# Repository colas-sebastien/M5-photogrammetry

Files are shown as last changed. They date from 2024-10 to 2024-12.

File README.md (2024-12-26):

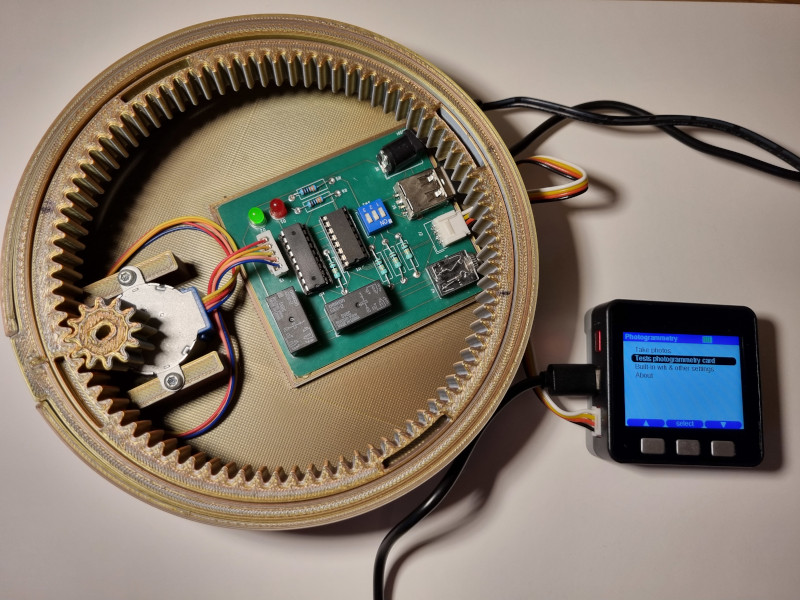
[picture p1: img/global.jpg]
Project photo

# M5 Photogrammetry Project
_Hardware and Software to do low cost photogrammetry_

## Introduction

Based on the following project [Arduino controlled photogrammetry 3D-scanner](https://www.thingiverse.com/thing:3958326) I decided to replace the arduino by any device I2C compatible. (for the moment M5Stack devices)

Here are the different parts of the project:
- 3D scanner updated to replace the arduino by an electronic card control thanks to I2C with a Grovre connector
- An electronic card to control the 3D-scanner. The card will be control by I2C and will control the stepper motor. The card is also able to control a camera thanks to a micro jack
- M5Stack arduino code to control the electronic card and take photos thanks to mobile phone (thanks to BlueTooth) or Flucard for Pentax (Thanks to Wifi)

# Hardware: 3D Scanner
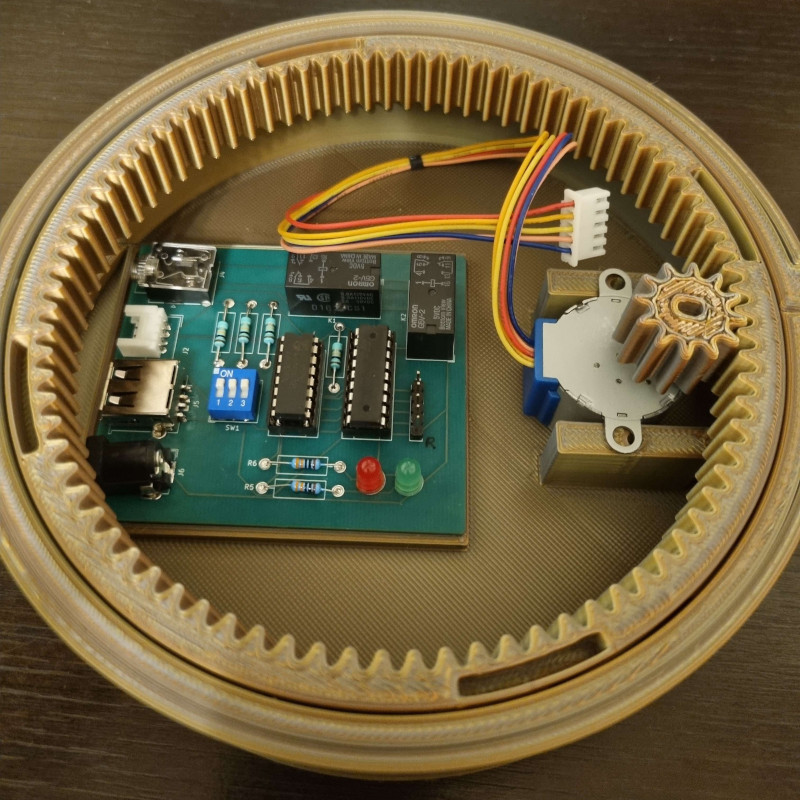
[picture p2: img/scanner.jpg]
3D Scanner


# Hardware: Electronic card
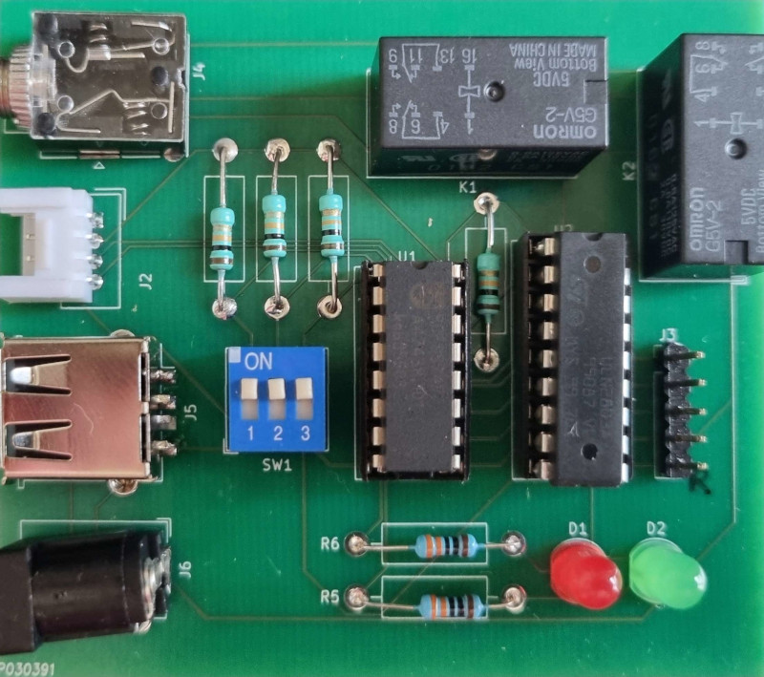
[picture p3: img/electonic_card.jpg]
Electronic Card


# Software: Arduino code for M5Stack
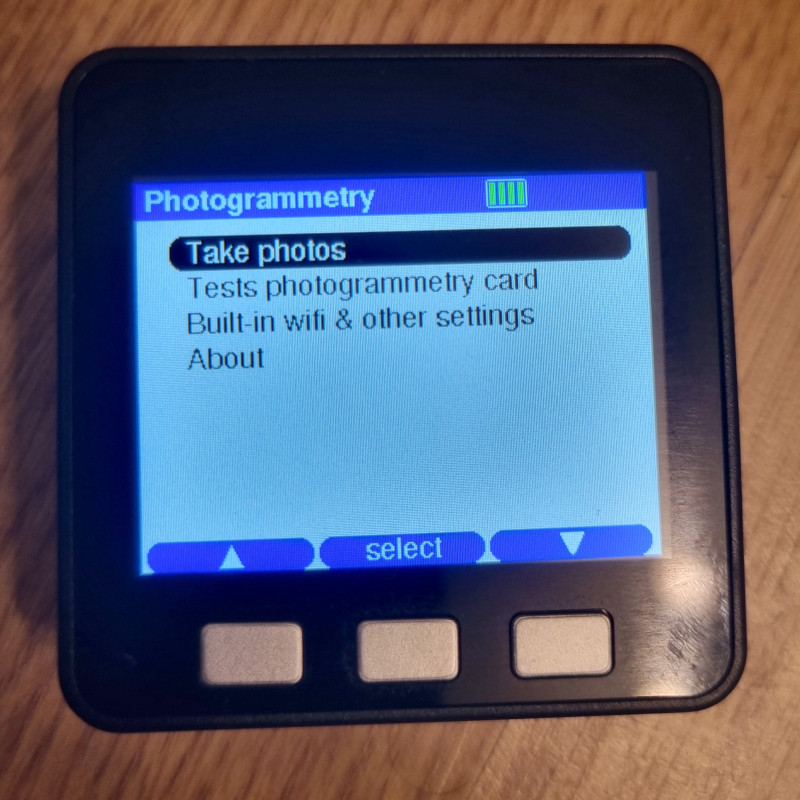
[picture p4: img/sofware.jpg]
Arduino code for M5Stack


# Software: Arduino code for M5StickC
TODO

# Photo shooting
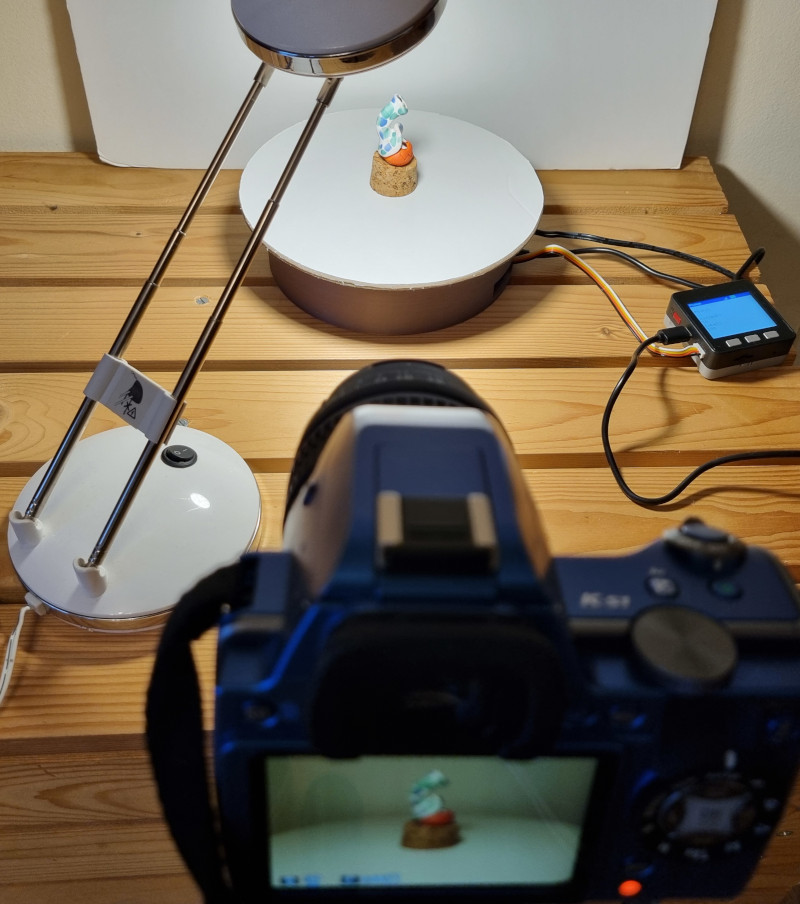
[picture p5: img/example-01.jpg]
Shooting


# Photogrammetry Software
Thanks to the previous steps we can have multiple photos of different angles of the object we want to reconstruct. It is now time to reconstruct the 3D Model.
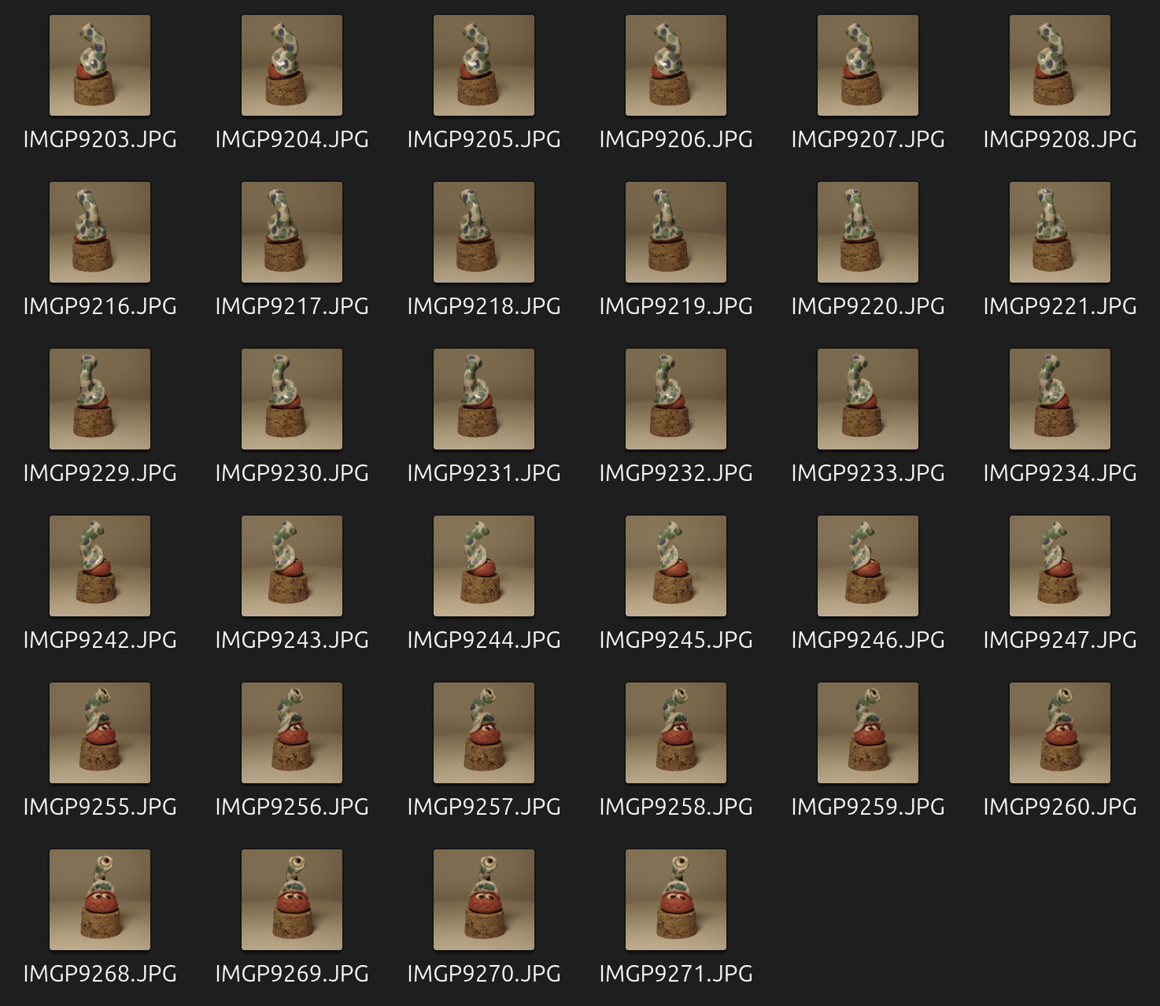
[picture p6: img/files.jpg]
Photos


Multiple Photogrammetry are available:
- [VisualSFM](http://ccwu.me/vsfm/)
- [MeshRoom](https://github.com/alicevision/meshroom/)
- [Regard3D](https://sourceforge.net/projects/regard3d/files/Regard3D/)

## VisualSFM
I created an installation script to Install [VisualSFM on Ubuntu 24.04](https://github.com/colas-sebastien/VisualSFM)
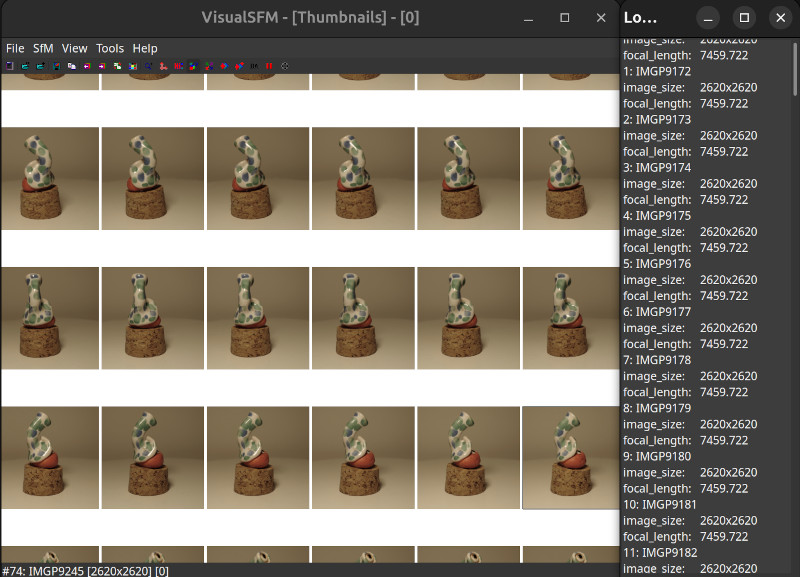
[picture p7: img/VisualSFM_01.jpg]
VisualSFM

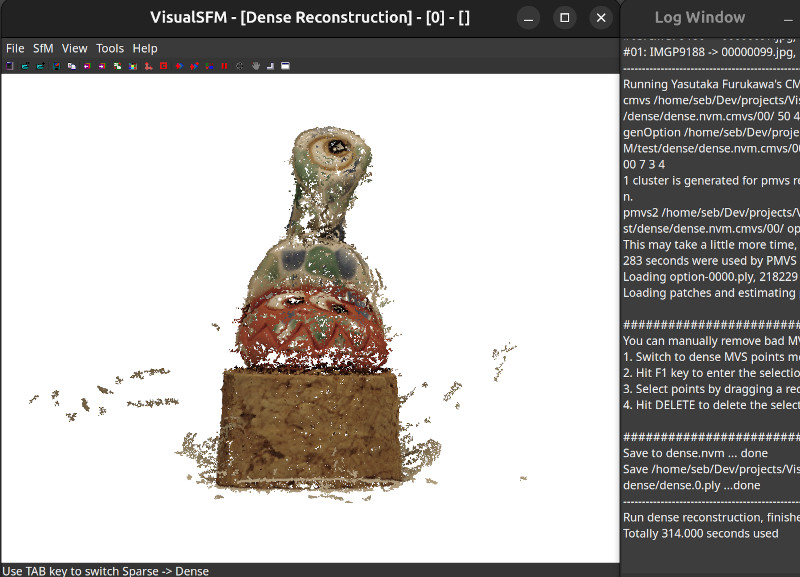
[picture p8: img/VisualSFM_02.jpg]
VisualSFM


# Meshing Software

## MeshLab

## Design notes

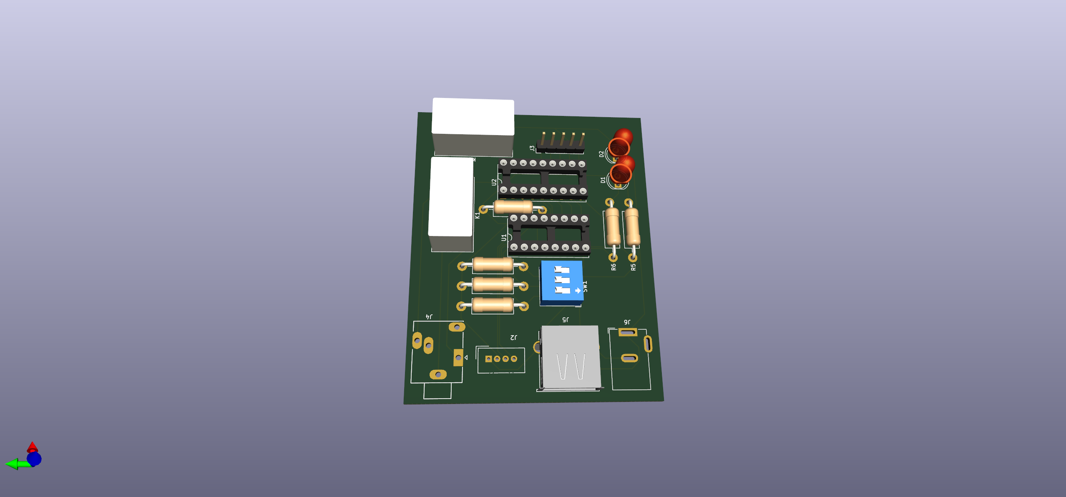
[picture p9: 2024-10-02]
i2c_stepper/i2c_stepper.png

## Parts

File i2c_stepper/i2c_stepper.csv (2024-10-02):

# | Reference | Qty | Value | Footprint | DNP
1 | D1, D2 | 2 | LED | LED_THT:LED_D5.0mm
2 | J2 | 1 | Conn_01x04 | Connector:NS-Tech_Grove_1x04_P2mm_Vertical
3 | J3 | 1 | Conn_01x05 | Connector_PinHeader_2.54mm:PinHeader_1x05_P2.54mm_Vertical
4 | J4 | 1 | AudioJack3 | Connector_Audio:Jack_3.5mm_Ledino_KB3SPRS_Horizontal
5 | J5 | 1 | USB_A | Connector_USB:USB_A_Stewart_SS-52100-001_Horizontal
6 | J6 | 1 | Barrel_Jack_Switch | Connector_BarrelJack:BarrelJack_GCT_DCJ200-10-A_Horizontal
7 | K1, K2 | 2 | RM84 | Relay_THT:Relay_DPDT_Finder_30.22
8 | R1, R2, R3, R4 | 4 | 10k | Resistor_THT:R_Axial_DIN0411_L9.9mm_D3.6mm_P15.24mm_Horizontal
9 | R5, R6 | 2 | 330 | Resistor_THT:R_Axial_DIN0411_L9.9mm_D3.6mm_P15.24mm_Horizontal
10 | SW1 | 1 | SW_DIP_x03 | Button_Switch_THT:SW_DIP_SPSTx03_Slide_9.78x9.8mm_W7.62mm_P2.54mm
11 | U1 | 1 | PCF8574 | Package_DIP:DIP-16_W7.62mm_Socket
12 | U2 | 1 | ULN2803A | Package_DIP:DIP-18_W7.62mm_Socket

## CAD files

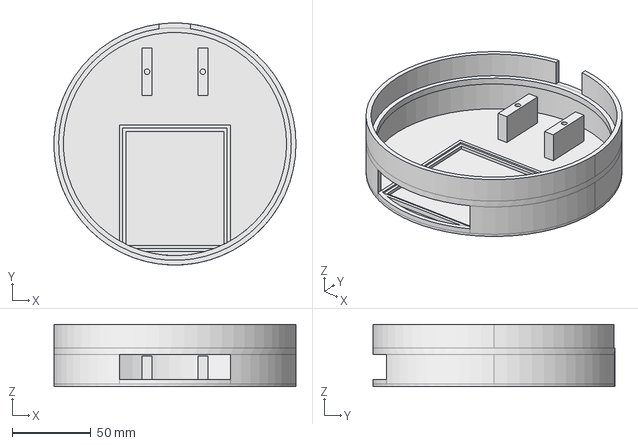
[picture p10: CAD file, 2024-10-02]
freecad/main.FCStd
153.9 x 154.0 x 39.5 mm

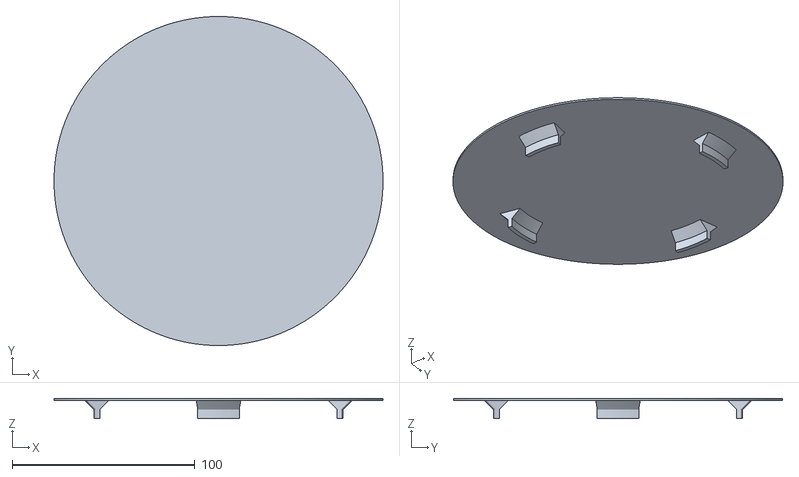
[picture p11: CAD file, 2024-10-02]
stl/plate_V1.stl
180.0 x 180.0 x 11.0

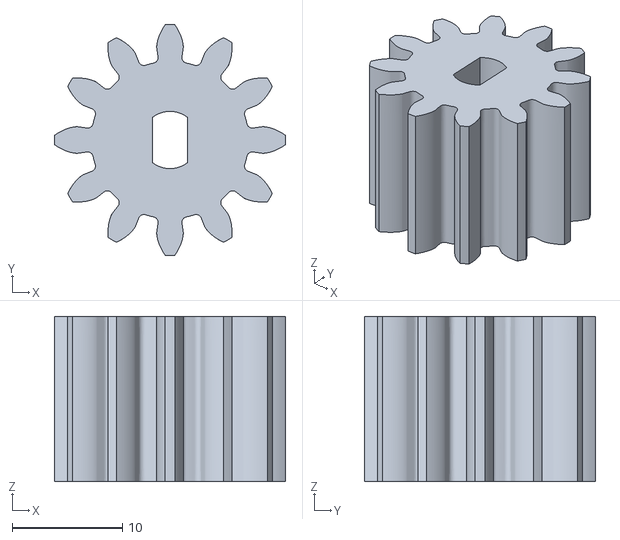
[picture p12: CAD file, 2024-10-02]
stl/Small_gear_V1.stl
21.0 x 21.0 x 15.0

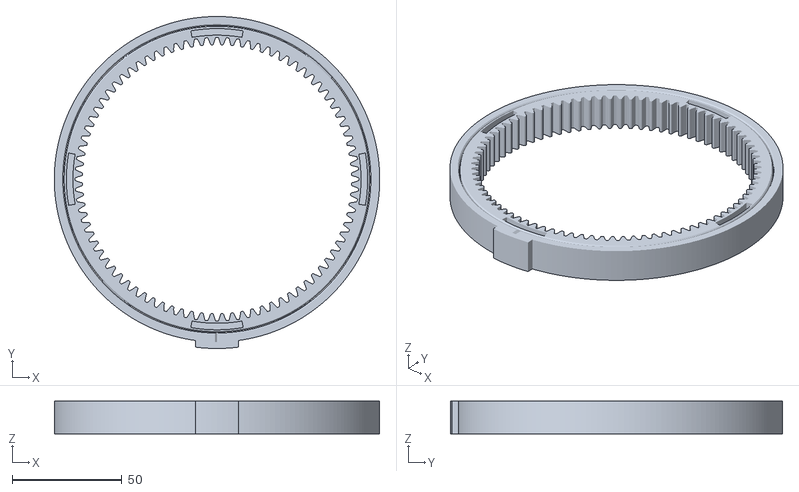
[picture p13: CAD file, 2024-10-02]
stl/bearing_V1_0.5_mm_gap.stl
148.0 x 151.0 x 15.0

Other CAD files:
stl/main.stl

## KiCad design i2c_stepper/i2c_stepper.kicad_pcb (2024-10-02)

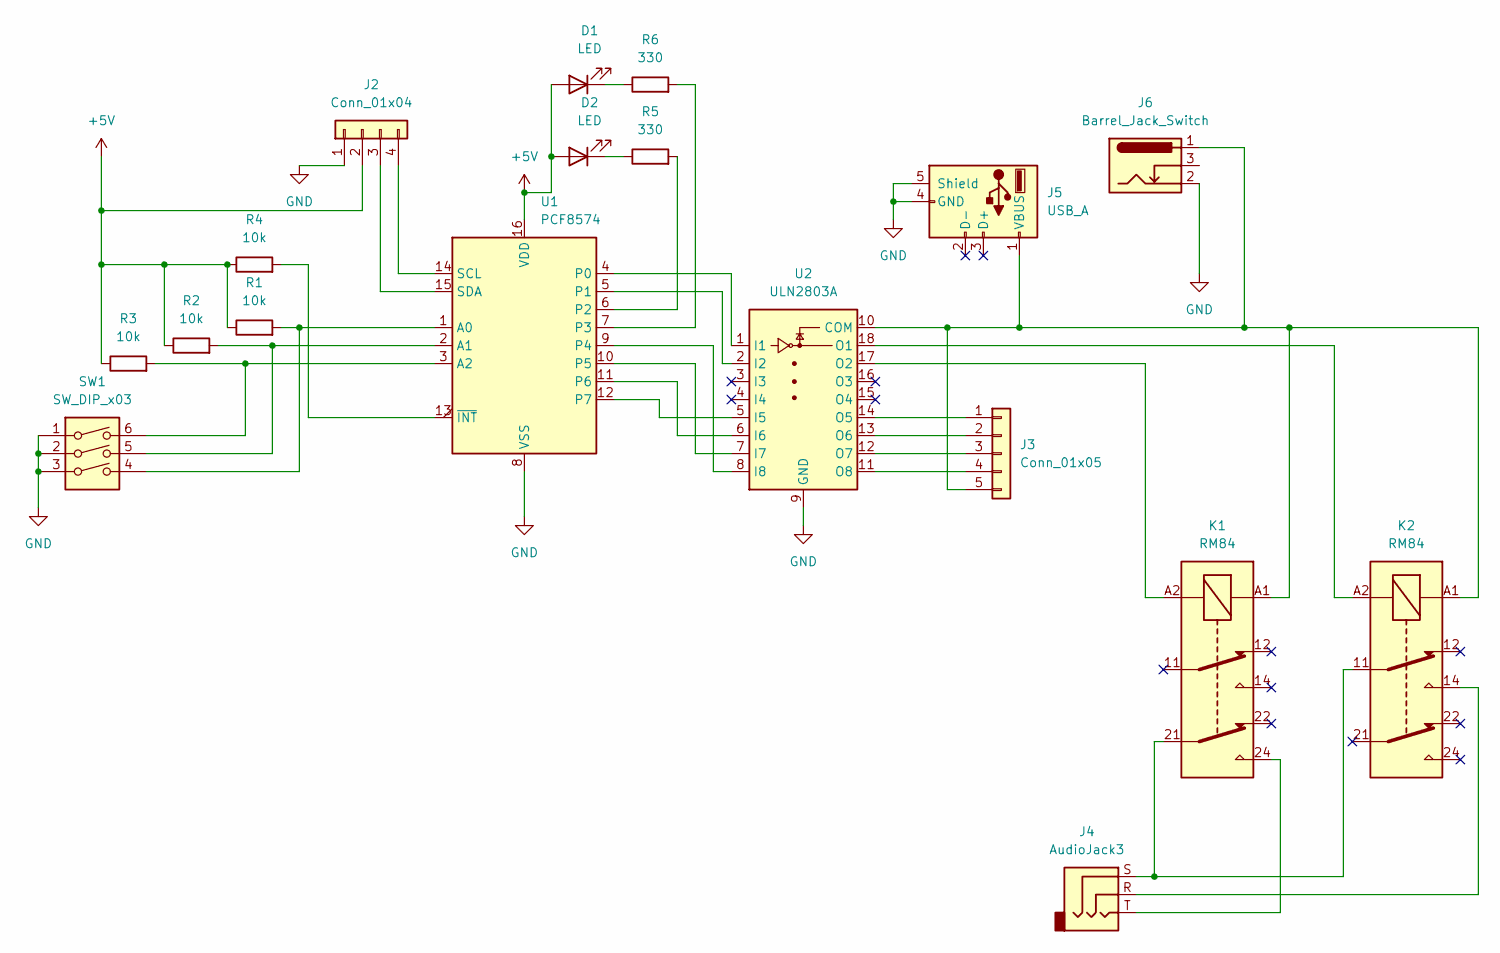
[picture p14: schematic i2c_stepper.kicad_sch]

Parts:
D1, D2: LED; LED_D5.0mm
J2: Conn_01x04; NS-Tech_Grove_1x04_P2mm_Vertical
J3: Conn_01x05; PinHeader_1x05_P2.54mm_Vertical
J4: AudioJack3; Jack_3.5mm_Ledino_KB3SPRS_Horizontal
J5: USB_A; USB_A_Stewart_SS-52100-001_Horizontal
J6: Barrel_Jack_Switch; BarrelJack_GCT_DCJ200-10-A_Horizontal
K1, K2: RM84; Relay_DPDT_Finder_30.22
R1, R2, R3, R4: 10k; R_Axial_DIN0411_L9.9mm_D3.6mm_P15.24mm_Horizontal
R5, R6: 330; R_Axial_DIN0411_L9.9mm_D3.6mm_P15.24mm_Horizontal
SW1: SW_DIP_x03; SW_DIP_SPSTx03_Slide_9.78x9.8mm_W7.62mm_P2.54mm
U1: PCF8574; DIP-16_W7.62mm_Socket
U2: ULN2803A; DIP-18_W7.62mm_Socket

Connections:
+5V: D1.2 (A), D2.2 (A), J2.2, R1.1, R2.1, R3.1, R4.1, U1.16 (VDD)
GND: J2.1, J5.4 (GND), J5.5 (Shield), J6.2, SW1.1, SW1.2, SW1.3, U1.8 (VSS), U2.9 (GND)
unnamed: D1.1 (K), R6.1
unnamed: D2.1 (K), R5.1
unnamed: J2.3, U1.15 (SDA)
unnamed: J2.4, U1.14 (SCL)
unnamed: J3.1, U2.14 (O5)
unnamed: J3.2, U2.13 (O6)
unnamed: J3.3, U2.12 (O7)
unnamed: J3.4, U2.11 (O8)
unnamed: J3.5, J5.1 (VBUS), J6.1, K1.A1, K2.A1, U2.10 (COM)
unnamed: J4.R, K2.14
unnamed: J4.S, K1.21, K2.11
unnamed: J4.T, K1.24
unnamed: R1.2, SW1.4, U1.1 (A0)
unnamed: R2.2, SW1.5, U1.2 (A1)
unnamed: R3.2, SW1.6, U1.3 (A2)
unnamed: U1.4 (P0), U2.1 (I1)
unnamed: U1.5 (P1), U2.2 (I2)
unnamed: R5.2, U1.6 (P2)
unnamed: R6.2, U1.7 (P3)
unnamed: U1.9 (P4), U2.8 (I8)
unnamed: U1.10 (P5), U2.7 (I7)
unnamed: U1.11 (P6), U2.6 (I6)
unnamed: U1.12 (P7), U2.5 (I5)
unnamed: R4.2, U1.13 (~INT)
unnamed: K2.A2, U2.18 (O1)
unnamed: K1.A2, U2.17 (O2)

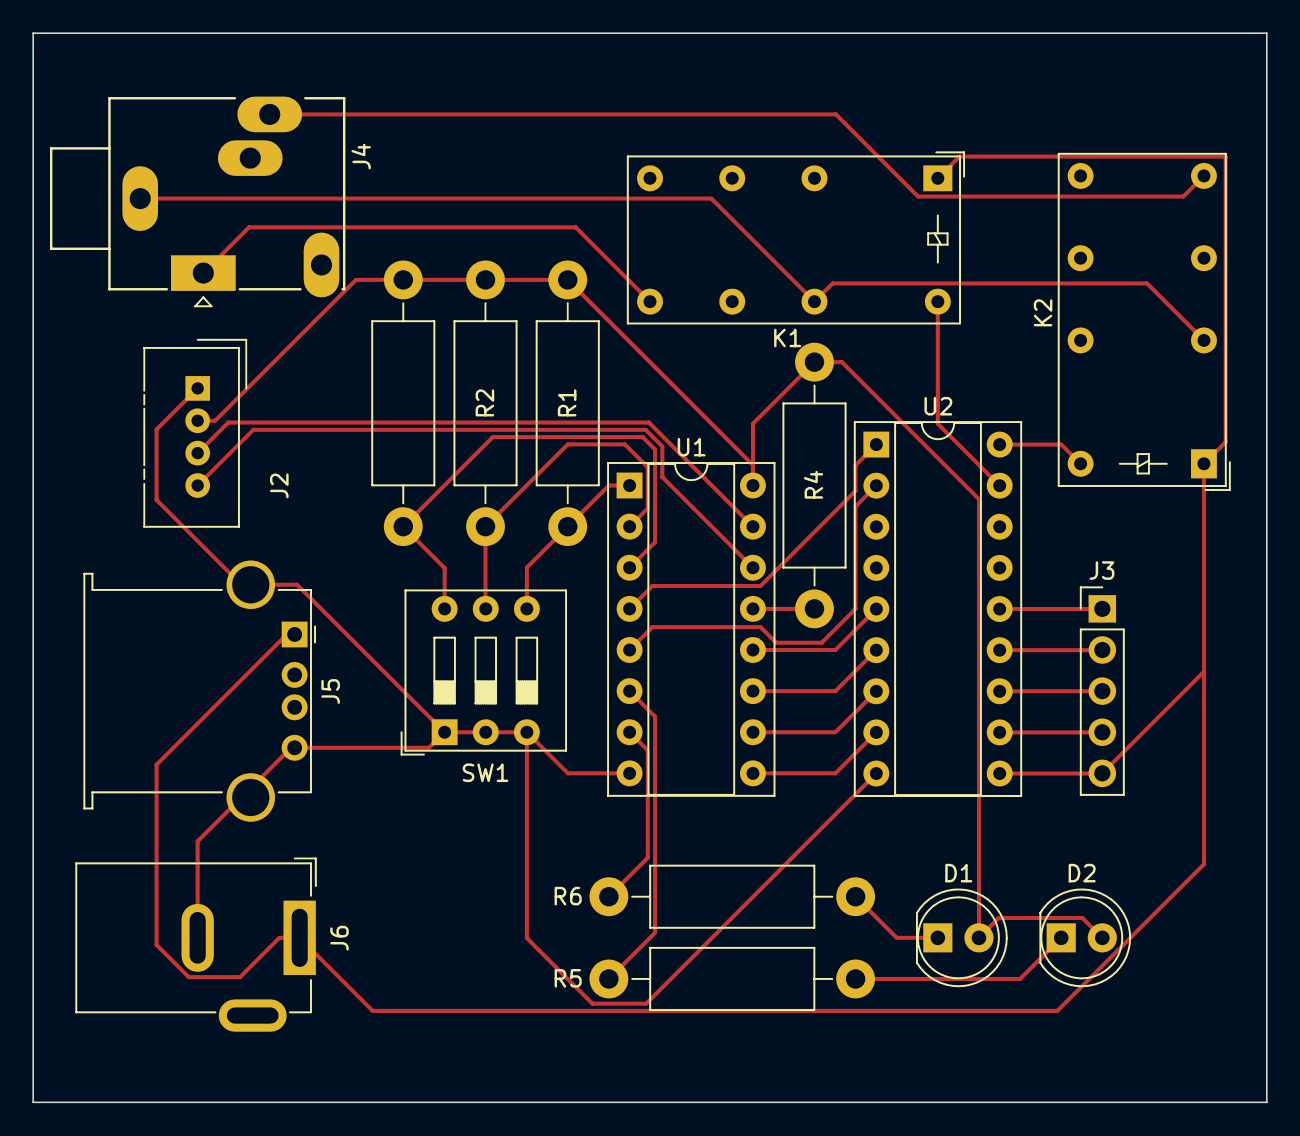
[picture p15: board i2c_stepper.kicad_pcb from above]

Board: 2 copper layers, 76.2 x 66.0 mm, 18 parts (0 on the bottom side), 28 nets.

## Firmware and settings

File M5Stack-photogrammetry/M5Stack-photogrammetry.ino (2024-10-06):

/*
 * Photogrammetry 3D-Scanner controlled by M5Stack
 *
 * The current file contains the GUI based on M5ez
 *
 * M5Stack Core (Basic): use Partition scheme: Hudge APP 
 */

#include <M5Stack.h>
#include <M5ez.h>

#include "M5Photogrammetry.h"

M5Photogrammetry m5photogrammetry;

uint8_t nb_photos       = 0;
bool    photos_jack     = false;
bool    photos_bt       = false;
bool    photos_flucard  = false;

/*
 * Function to detect I2C port in used
 */
void menu_tests_i2c()
{
  int address;
  int error;
  ez.header.show("I2C scanning Address");
  ez.canvas.lmargin(5);
  ez.canvas.font(&FreeMono12pt7b);
  ez.canvas.println("");
  for (address = 1; address < 127; address++) {
      Wire.beginTransmission(address);  
      error = Wire.endTransmission(); 
      if (error == 0) {
          ez.canvas.print(address, HEX);
          ez.canvas.print(" ");
      } else
          ez.canvas.print(".");
  }
  ez.buttons.wait("OK");
}

/*
 * Function to test leds
 */
void menu_tests_leds()
{
  ez.header.show("Leds test");
  ez.canvas.lmargin(5);
  ez.canvas.font(&FreeMono12pt7b);
  ez.canvas.println("");
  ez.canvas.println("Press buttons");
  ez.canvas.println("to test leds");
  ez.buttons.show("OK # Green # Red");
  while (true) 
  {
    String btnpressed = ez.buttons.poll();
    if (btnpressed == "OK") break;
    
    if (btnpressed == "Green")
    {
      m5photogrammetry.ledGreenToggle();
    }
    if (btnpressed == "Red")
    {
      m5photogrammetry.ledRedToggle();
    }    
  }
}

/*
 * Function to test if photos can be taken thanks to jack connector
 */
void menu_tests_jack()
{
  ez.header.show("Jack test");
  ez.canvas.lmargin(5);
  ez.canvas.font(&FreeMono12pt7b);
  ez.canvas.println("");
  ez.canvas.println("Press buttons");
  ez.canvas.println("to test leds");
  ez.buttons.show("OK # Focus # Shoot");
  while (true) 
  {
    String btnpressed = ez.buttons.poll();
    if (btnpressed == "OK") break;
    
    if (btnpressed == "Focus")
    {
      m5photogrammetry.jackFocusToggle();
    }
    if (btnpressed == "Shoot")
    {
      m5photogrammetry.jackShootToggle();
    }    
  }
}

/*
 * Function to test if photos can be taken thanks Pentax Flucard
 */
void menu_tests_flucard()
{
  int cmpt=0;
  ez.header.show("Flucard test");
  ez.canvas.lmargin(5);
  ez.canvas.font(&FreeMono12pt7b);
  ez.canvas.println();
  ez.canvas.print("Trying to connect");
  m5photogrammetry.flucardStart();

  while ((cmpt < 20) && (!m5photogrammetry.flucardIsConnected()))  // Waiting for connection
  {
    ez.canvas.print(".");
    cmpt++;
  }
  bool flucard=m5photogrammetry.flucardIsConnected();

  ez.canvas.println();
  if (flucard)
  {    
    ez.canvas.println("Connected");
  }
  else
  {
    ez.canvas.println("Can't connect");
  }

  ez.buttons.show("OK # Focus # Shoot");
  while (true) 
  {
    String btnpressed = ez.buttons.poll();
    if (btnpressed == "OK") break;
    
    if (btnpressed == "Focus")
    {
      m5photogrammetry.flucardFocusToggle();
    }
    if (btnpressed == "Shoot")
    {
      m5photogrammetry.flucardShootToggle();
    }    
  }
}

/*
 * Function to test Bluetooth
 */
void menu_tests_bt()
{
  int cmpt=0;
  ez.header.show("Bluetooth Test");
  ez.canvas.lmargin(5);
  ez.canvas.font(&FreeMono12pt7b);
  ez.canvas.println();
  ez.canvas.print("Trying to connect");
  m5photogrammetry.bluetoothStart();

  while ((cmpt < 200) && (!m5photogrammetry.bluetoothIsConnected()))  // Waiting for connection
  {
    if (cmpt%2==0)
    {
      ez.canvas.print(".");
    }
    delay(100);
    cmpt++;
  }
  bool bluetooth=m5photogrammetry.bluetoothIsConnected();

  ez.canvas.println();
  if (bluetooth)
  {    
    ez.canvas.println("Connected");
  }
  else
  {
    ez.canvas.println("Can't connect");
  }  

  ez.buttons.show("OK # Shoot # OFF");
  while (true) 
  {
    String btnpressed = ez.buttons.poll();
    if (btnpressed == "OK") break;
    
    if (btnpressed == "Shoot") 
    {
      m5photogrammetry.bluetoothTakePhoto();
    }

    if (btnpressed == "OFF")
    {
      m5photogrammetry.bluetoothStop();
    }    
  }
}

void menu_tests_motor()
{
  ez.header.show("Stepper motor test");
  ez.canvas.lmargin(5);
  ez.canvas.font(&FreeMono12pt7b);
  ez.canvas.println("");
  ez.canvas.println("Forward");

  m5photogrammetry.motorForward();
  for (int i=0;i<PHOTOGRAMMETRY_MOTOR_ROTATION;i++)
  {
    m5photogrammetry.motorNextStep();
    delay(1);
  }
  ez.canvas.println("Stop");
  m5photogrammetry.ledGreenOn();
  m5photogrammetry.ledRedOff();
  delay(4000);
  ez.canvas.println("Backward");
  m5photogrammetry.motorBackward();
  for (int i=0;i<PHOTOGRAMMETRY_MOTOR_ROTATION;i++)
  {
    m5photogrammetry.motorNextStep();
    delay(1);
  }
  m5photogrammetry.ledGreenOn();
  m5photogrammetry.ledRedOff();
  ez.buttons.wait("OK");
}

void setup() {
  M5.begin();                       // Init M5Stack(Initial I2C is also included).
  M5.Power.begin();                 // Init power
  m5photogrammetry.begin();         // Initialize the electronic card: green led => on

  #include <themes/default.h>
  #include <themes/dark.h>
  ezt::setDebug(INFO);
  ez.begin();    
}

void loop() {
  ezMenu mainmenu(PHOTOGRAMMETRY_PROJECT);
  mainmenu.txtSmall();
  mainmenu.addItem("Take photos", mainmenu_photos);
  mainmenu.addItem("Tests photogrammetry card", mainmenu_tests);
  mainmenu.addItem("Built-in wifi & other settings", ez.settings.menu);
  mainmenu.addItem("About", mainmenu_about);
  mainmenu.upOnFirst("last|up");
  mainmenu.downOnLast("first|down");
  mainmenu.run();
}

void mainmenu_tests()
{
  ezMenu submenu("Test");
  submenu.txtSmall();
  submenu.buttons("up#Back#select##down#");
  submenu.addItem("I2C",menu_tests_i2c);
  submenu.addItem("Leds",menu_tests_leds);
  submenu.addItem("Bluetooth",menu_tests_bt);
  submenu.addItem("Jack",menu_tests_jack);
  submenu.addItem("Pentax Flucard",menu_tests_flucard);
  submenu.addItem("Motor",menu_tests_motor);
  submenu.run();  
}

void mainmenu_photos()
{
  String nbSteps="Nb photos: ";
  ezMenu submenu("Photos");
  submenu.txtSmall();
  submenu.buttons("up#Back#select##down#");
  submenu.addItem("Set the number of photos",menu_photos_nb);
  submenu.addItem("Take photos via Jack",menu_photos_jack);
  submenu.addItem("Take photos via BlueTooth",menu_photos_bt);
  submenu.addItem("Take photos via Flucard",menu_photos_flucard);
  submenu.addItem("Start taking photos",menu_photos_start);
  submenu.run();  
}


void menu_photos_start_txt(uint8_t photo_id)
{
  ez.canvas.clear();
  ez.header.show("Photos");
  ez.canvas.lmargin(5);
  ez.canvas.font(&FreeMono12pt7b);
  ez.canvas.println("");  
  ez.canvas.println("current:");  
  ez.canvas.println(photo_id);
  ez.canvas.println("total:");  
  ez.canvas.println(nb_photos);
}

void menu_photos_start()
{
  uint8_t photo_id=0;
  int nb_steps_todo=PHOTOGRAMMETRY_MOTOR_ROTATION/nb_photos;
  int current_photo=1;

  menu_photos_start_txt(current_photo);

  m5photogrammetry.motorForward();
  for (int i=0;i<PHOTOGRAMMETRY_MOTOR_ROTATION;i++)
  {
    if (i%nb_steps_todo==0)
    {
      delay(100);
      if (photos_jack)
      {
        m5photogrammetry.jackShootPress();
        delay(500);
        m5photogrammetry.jackShootRelease();
      }
      if (photos_bt)
      {
        m5photogrammetry.bluetoothTakePhoto();
      } 
      if (photos_flucard)
      {
        m5photogrammetry.flucardShootToggle();
      }      
      if (current_photo<=nb_photos)
      {
        menu_photos_start_txt(current_photo);
      }
      current_photo++;      
    }
    m5photogrammetry.motorNextStep();
    delay(1);
  }
  delay(1000);
  m5photogrammetry.motorBackward();
  for (int i=0;i<PHOTOGRAMMETRY_MOTOR_ROTATION;i++)
  {
    m5photogrammetry.motorNextStep();
    delay(1);
  }

  ez.buttons.show("OK");
  while (true) 
  {
    String btnpressed = ez.buttons.poll();
    if (btnpressed == "OK") break;
  }    
}

void menu_photos_jack_txt()
{
  ez.canvas.clear();
  ez.header.show("Photos with Jack");
  ez.canvas.lmargin(5);
  ez.canvas.font(&FreeMono12pt7b);  
  ez.canvas.println("");
  ez.canvas.println("Take photos with");
  ez.canvas.println("Jack:");
  ez.canvas.println("");
  if (photos_jack)
  {
    ez.canvas.println("Enabled");
  }
  else
  {
    ez.canvas.println("Disabled");
  }  
}

void menu_photos_bt_txt()
{
  ez.canvas.clear();
  ez.header.show("Photos with BlueTooth");
  ez.canvas.lmargin(5);
  ez.canvas.font(&FreeMono12pt7b);  
  ez.canvas.println("");
  ez.canvas.println("Take photos with");
  ez.canvas.println("BlueTooth:");
  ez.canvas.println("");
  if (photos_bt)
  {
    ez.canvas.println("Enabled");
  }
  else
  {
    ez.canvas.println("Disabled");
  }  
}

void menu_photos_flucard_txt()
{
  ez.canvas.clear();
  ez.header.show("Photos with Flucard");
  ez.canvas.lmargin(5);
  ez.canvas.font(&FreeMono12pt7b);  
  ez.canvas.println("");
  ez.canvas.println("Take photos with");
  ez.canvas.println("FluCard:");
  ez.canvas.println("");
  if (photos_flucard)
  {
    ez.canvas.println("Enabled");
  }
  else
  {
    ez.canvas.println("Disabled");
  }  
}

void menu_photos_jack()
{
  menu_photos_jack_txt();
  ez.buttons.show("OK # ON # OFF");
  while (true) 
  {
    String btnpressed = ez.buttons.poll();
    if (btnpressed == "OK") break;
    
    if (btnpressed == "ON")
    {
      photos_jack=true;      
      menu_photos_jack_txt();
    }
    if (btnpressed == "OFF")
    {      
      photos_jack=false;
      menu_photos_jack_txt();
    }    
  }  
}

void menu_photos_bt()
{
  menu_photos_bt_txt();
  ez.buttons.show("OK # ON # OFF");
  while (true) 
  {
    String btnpressed = ez.buttons.poll();
    if (btnpressed == "OK") break;
    
    if (btnpressed == "ON")
    {
      int cmpt=0;
      m5photogrammetry.bluetoothStart();
      while ((cmpt < 200) && (!m5photogrammetry.bluetoothIsConnected()))  // Waiting for connection
      {
        if (cmpt%2==0)
        {
          ez.canvas.print(".");
        }
        delay(100);
        cmpt++;
      }
      photos_bt=m5photogrammetry.bluetoothIsConnected();;      
      menu_photos_bt_txt();
    }
    if (btnpressed == "OFF")
    {      
      photos_bt=false;
      menu_photos_bt_txt();
    }    
  }  
}

void menu_photos_flucard()
{
  menu_photos_flucard_txt();
  ez.buttons.show("OK # ON # OFF");
  while (true) 
  {
    String btnpressed = ez.buttons.poll();
    if (btnpressed == "OK") break;
    
    if (btnpressed == "ON")
    {
      int cmpt=0;
      m5photogrammetry.flucardStart();
      while ((cmpt < 20) && (!m5photogrammetry.flucardIsConnected()))  // Waiting for connection
      {
        ez.canvas.print(".");
        cmpt++;
      }
      photos_flucard=m5photogrammetry.flucardIsConnected();    
      menu_photos_flucard_txt();
    }
    if (btnpressed == "OFF")
    {      
      photos_flucard=false;
      menu_photos_flucard_txt();
    }    
  }  
}

void menu_photos_nb_txt()
{
  ez.canvas.clear();
  ez.header.show("Photos");
  ez.canvas.lmargin(5);
  ez.canvas.font(&FreeMono12pt7b);  
  ez.canvas.println("");
  ez.canvas.println("Number of photos:");
  ez.canvas.println("");
  ez.canvas.println(nb_photos);
  ez.canvas.println("");
}
/*
 * Function to test if photos can be taken thanks to jack connectoer
 */
void menu_photos_nb()
{  
  menu_photos_nb_txt();
  ez.buttons.show("OK # +1 # +10");
  while (true) 
  {
    String btnpressed = ez.buttons.poll();
    if (btnpressed == "OK") break;
    
    if (btnpressed == "+1")
    {
      nb_photos+=1;      
      menu_photos_nb_txt();
    }
    if (btnpressed == "+10")
    {      
      nb_photos+=10;
      menu_photos_nb_txt();
    }    
  }
}

void mainmenu_about() { 
  String s1=PHOTOGRAMMETRY_PROJECT;
  String s2=PHOTOGRAMMETRY_VERSION;
  String s3=PHOTOGRAMMETRY_AUTHOR;
  ez.msgBox(PHOTOGRAMMETRY_PROJECT, s1+" | "+s2+" | | "+s3);
}

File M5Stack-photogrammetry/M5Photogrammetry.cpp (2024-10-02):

#include "M5Photogrammetry.h"

M5Photogrammetry::M5Photogrammetry()
{
  bleKeyboard.setName(PHOTOGRAMMETRY_PROJECT);  
}

void M5Photogrammetry::bluetoothStart()
{
  bleKeyboard.begin();                                  // Initialize Bluetooth
}

bool M5Photogrammetry::bluetoothIsConnected()
{
  return bleKeyboard.isConnected();                     // test if bluetooth is connected
}

void M5Photogrammetry::bluetoothTakePhoto()             // Press Return to take a photo
{
  if (bleKeyboard.isConnected())
  {
    bleKeyboard.write(KEY_RETURN);
  }
}

void M5Photogrammetry::bluetoothStop()                  // Stop Bluetooth
{
  bleKeyboard.end();
}

void M5Photogrammetry::i2cWrite(uint8_t _data) {
  Wire.beginTransmission(PHOTOGRAMMETRY_I2C_ADDR);  // Starting transmission
  Wire.write(_data);                                // Sending data
  Wire.endTransmission();                           // Ending transmission
}

void M5Photogrammetry::i2cToggle(uint8_t _data)
{
    ic2_data=ic2_data ^ _data;
    i2cWrite(ic2_data);  
}

void M5Photogrammetry::i2cOn(uint8_t _data)
{
    ic2_data=ic2_data & ~_data;
    i2cWrite(ic2_data); 
}

void M5Photogrammetry::i2cOff(uint8_t _data)
{
    ic2_data=ic2_data | _data;
    i2cWrite(ic2_data); 
}

void M5Photogrammetry::ledGreenToggle()
{
    i2cToggle(PHOTOGRAMMETRY_LED_GREEN);
}

void M5Photogrammetry::ledGreenOn()
{
    i2cOn(PHOTOGRAMMETRY_LED_GREEN);
}

void M5Photogrammetry::ledGreenOff()
{
    i2cOff(PHOTOGRAMMETRY_LED_GREEN);
}

void M5Photogrammetry::ledRedToggle()
{
    i2cToggle(PHOTOGRAMMETRY_LED_RED);
}

void M5Photogrammetry::ledRedOn()
{
    i2cOn(PHOTOGRAMMETRY_LED_RED);
}

void M5Photogrammetry::ledRedOff()
{
    i2cOff(PHOTOGRAMMETRY_LED_RED);
}

void M5Photogrammetry::jackFocusToggle()
{
  i2cToggle(PHOTOGRAMMETRY_JACK_FOCUS);
}

void M5Photogrammetry::jackFocusPress()
{
  i2cOn(PHOTOGRAMMETRY_JACK_FOCUS);
}

void M5Photogrammetry::jackFocusRelease()
{
  i2cOff(PHOTOGRAMMETRY_JACK_FOCUS);
}

void M5Photogrammetry::jackShootToggle()
{
  i2cToggle(PHOTOGRAMMETRY_JACK_SHOOT);
}

void M5Photogrammetry::jackShootPress()
{
  i2cOff(PHOTOGRAMMETRY_JACK_SHOOT);
}

void M5Photogrammetry::jackShootRelease()
{
  i2cOn(PHOTOGRAMMETRY_JACK_SHOOT);
}

void M5Photogrammetry::flucardStart()
{
  wifiMulti.addAP(PHOTOGRAMMETRY_FLUCARD_SSID, PHOTOGRAMMETRY_FLUCARD_PASSWORD);  
}

bool M5Photogrammetry::flucardIsConnected()
{
  return (wifiMulti.run() ==  WL_CONNECTED);
}

void M5Photogrammetry::flucardFocusToggle()
{
  httpClient.begin(PHOTOGRAMMETRY_FLUCARD_FOCUS);
  httpClient.GET();
  httpClient.end();
}

void M5Photogrammetry::flucardShootToggle()
{  
  httpClient.begin(PHOTOGRAMMETRY_FLUCARD_SHOOT);
  httpClient.GET();
  httpClient.end();
}

void M5Photogrammetry::flucardStop()
{
  
}

void M5Photogrammetry::begin()
{
  ledGreenOn(); 
  ledRedOff();
}

void M5Photogrammetry::motorForward()
{
  motor_forward=true;
}

void M5Photogrammetry::motorBackward()
{
  motor_forward=false;
}

void M5Photogrammetry::motorNextStep()
{  
  if (motor_forward)
  { 
    motor_current_step++;
    if (motor_current_step>=PHOTOGRAMMETRY_MOTOR_STEPS)
    {
      motor_current_step=0;
    }
  }
  else
  {
    if (motor_current_step==0)
    {
      motor_current_step=PHOTOGRAMMETRY_MOTOR_STEPS;
    }
    motor_current_step--;
  }
  ic2_data=motor_steps[motor_current_step];
  i2cWrite(ic2_data);
}

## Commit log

2024-10-02 M5Stack code + PCB extension card + 3D Model
2024-10-06 current photo number modification
